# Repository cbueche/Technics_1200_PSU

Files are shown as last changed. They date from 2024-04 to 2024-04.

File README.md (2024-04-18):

# DC PSU for the Technics SL-1200 

An external PSU (linear power supply unit) for the Technics SL-1200 turntable. Originaly designed by user 6L6 published on DIYaudio.com forum in 2013.

## License

This project is licensed under the terms of the CERN Open Hardware Licence Version 2, permissive variant [CERN-OHL-P](cern_ohl_p_v2).

## Schematics

The [schematic](schema_v4.pdf) is an export from the kicad files.

## PCB

I designed a PCB for this project, the [kicad](kicad/) directory contains everything needed : the schematic, the PCB design, etc. I updated those files to Kicad 8. There is a zip file that I was able to use to order 5 PCBs from PCBway, the minimal order quantity was 5 in May 2023. The four remaining PCBs were sold quickly.

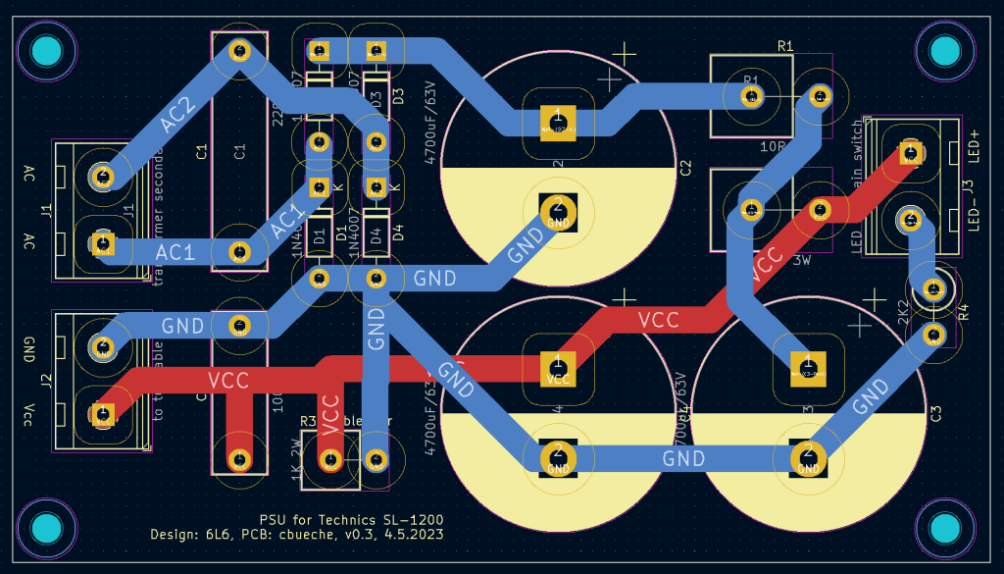
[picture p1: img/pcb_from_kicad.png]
PCB


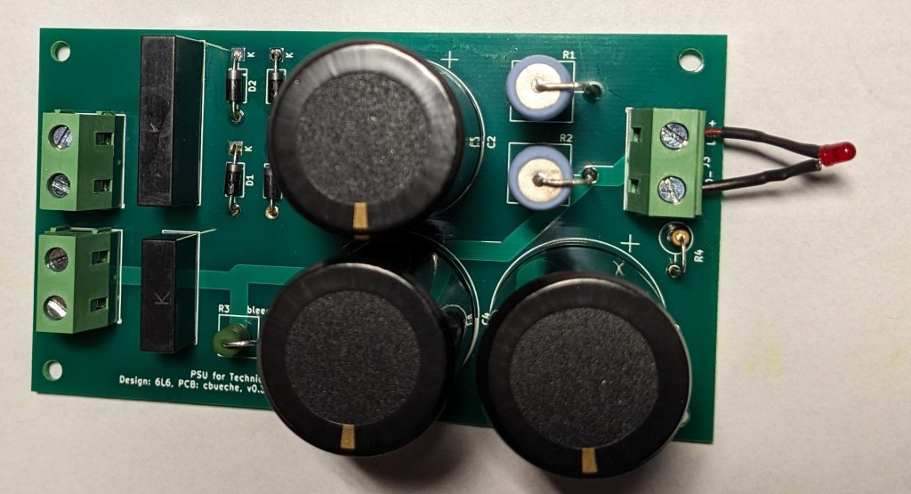
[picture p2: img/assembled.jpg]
assembled


The side-holes are not connected to anything, proper grounding is your task. I recommend connecting the input earth to the case. As designed, the DC output (GND and Vcc) are floating.

## BOM

Sorry, no BOM, see the CSV file in the [kicad](kicad/) directory, the footprint column provides some info on the spacing. In general, very standard components can be used. Big capacitors are 10mm snap-in, connectors use 7.5mm spacing.

## Resources

- the [original thread](https://www.diyaudio.com/community/threads/technics-sl-1200-dc-power-supply.238618/) on DIYaudio
- original author : 6L6, DIYaudio.com

## concept used in my personal case

- external DC PSU unit
- regulator and probe switch from [KAB USA](https://www.kabusa.com)

## case

The original transformer and this PCB did somewhat tightly fit into a Hifi 2000 Galaxy case model GX183 (80x124x230). A tight fit so check before drilling holes.

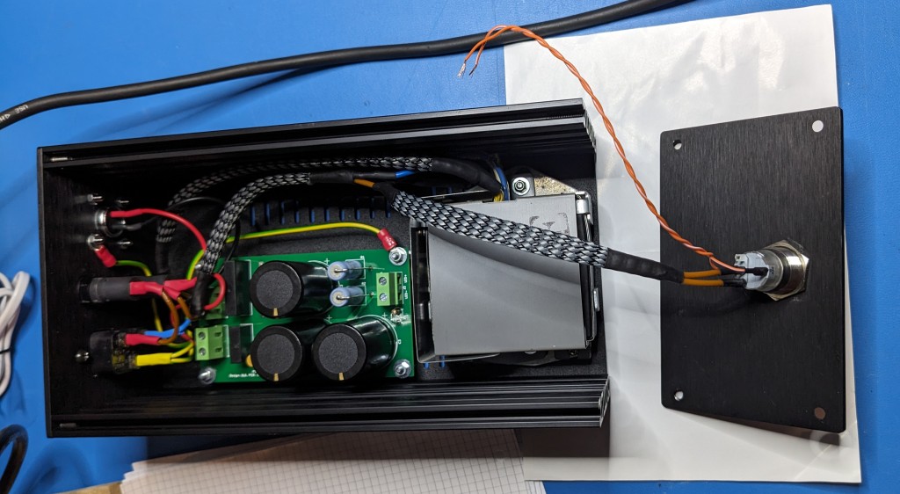
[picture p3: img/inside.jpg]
inside


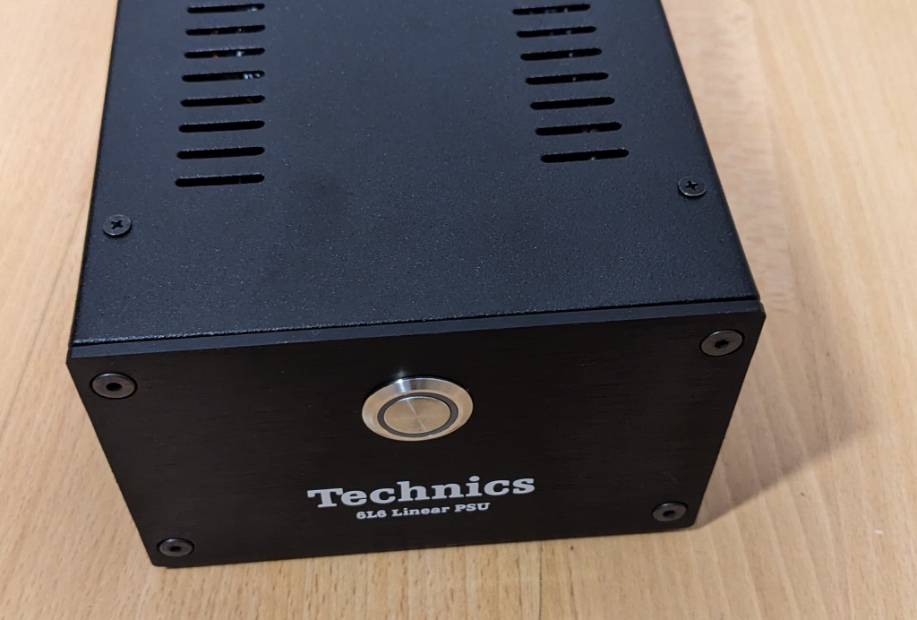
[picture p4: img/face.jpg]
face


## fuses

These fuse values are appropriate for 230V.

- top, input : AC, T 250 mA
- bottom, output : DC, T 1 A

## DC cable

- 2 x 0.75
- pin 1 : brown : GND
- pin 2 : blue : Vcc

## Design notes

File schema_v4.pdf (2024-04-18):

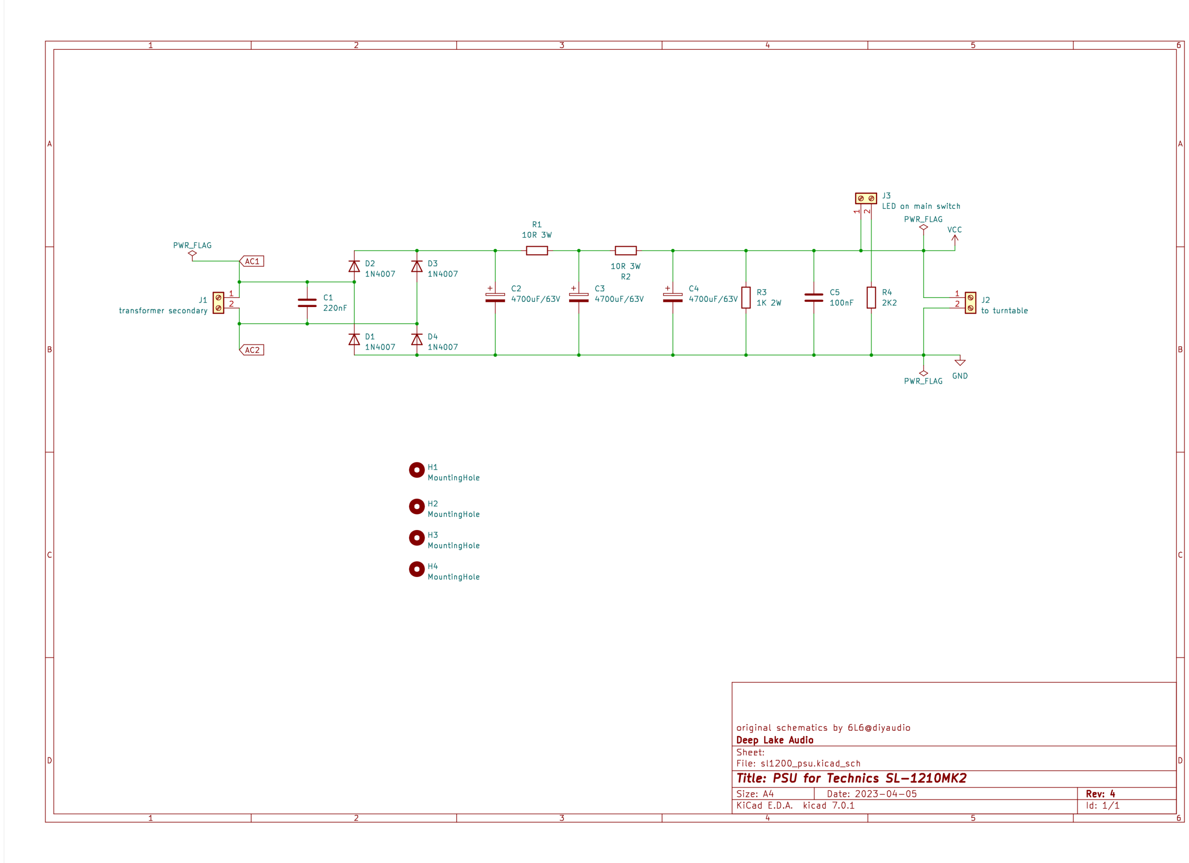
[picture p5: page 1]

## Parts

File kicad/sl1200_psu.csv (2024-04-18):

Source: | /home/cbueche/Data/Audio/tourne_disque/Technics_1210_MK2/PSU/kicad/sl1200_psu.kicad_sch
Date: | Thu Mar 9 16:44:58 2023
Tool: | Eeschema (7.0.0)
Generator: | /usr/share/kicad/plugins/bom_csv_grouped_by_value_with_fp.py
Component Count: | 16
Ref | Qnty | Value | Cmp name | Footprint | Description | Vendor | DNP
C1 | 1 | 220nF | C | Capacitor_THT:C_Rect_L26.5mm_W6.0mm_P22.50mm_MKS4 | Unpolarized capacitor
C2, C3, C4 | 3 | 4700uF/63V | C_Polarized | Capacitor_THT:CP_Radial_D26.0mm_P10.00mm_SnapIn | Polarized capacitor
C5 | 1 | 100nF | C | Capacitor_THT:C_Rect_L26.5mm_W6.0mm_P22.50mm_MKS4 | Unpolarized capacitor
D1, D2, D3, D4 | 4 | 1N4007 | 1N4007 | Diode_THT:D_DO-41_SOD81_P10.16mm_Horizontal | 1000V 1A General Purpose Rectifier Diode, DO-41
J1 | 1 | transformer secondary | Screw_Terminal_01x02 | TerminalBlock_RND:TerminalBlock_RND_205-00067_1x02_P7.50mm_Horizontal | Generic screw terminal, single row, 01x02, script generated (kicad-library-utils/schlib/autogen/connector/)
J2 | 1 | to turntable | Screw_Terminal_01x02 | TerminalBlock_RND:TerminalBlock_RND_205-00067_1x02_P7.50mm_Horizontal | Generic screw terminal, single row, 01x02, script generated (kicad-library-utils/schlib/autogen/connector/)
J3 | 1 | LED on main switch | Screw_Terminal_01x02 | TerminalBlock_RND:TerminalBlock_RND_205-00067_1x02_P7.50mm_Horizontal | Generic screw terminal, single row, 01x02, script generated (kicad-library-utils/schlib/autogen/connector/)
R1, R2 | 2 | 10R 3W | R | Resistor_THT:R_Axial_Power_L38.0mm_W9.0mm_P40.64mm | Resistor
R3 | 1 | 1K 2W | R | Resistor_THT:R_Axial_Power_L20.0mm_W6.4mm_P5.08mm_Vertical | Resistor
R4 | 1 | 2K2 2W | R | Resistor_THT:R_Axial_Power_L20.0mm_W6.4mm_P5.08mm_Vertical | Resistor

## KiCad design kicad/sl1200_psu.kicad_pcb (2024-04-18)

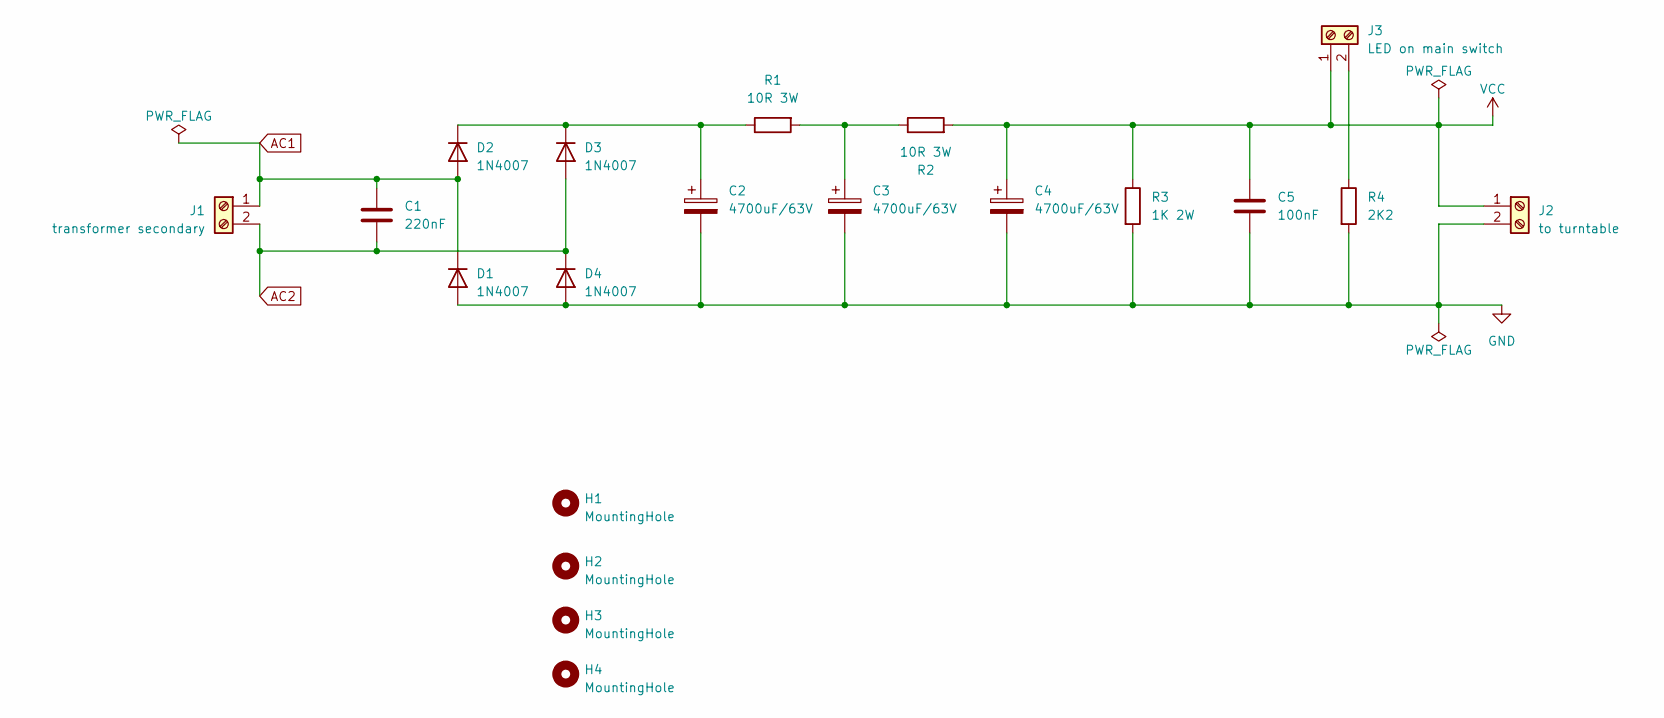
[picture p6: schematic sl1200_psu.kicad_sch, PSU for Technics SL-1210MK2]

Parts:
C1: 220nF; C_Rect_L26.5mm_W6.0mm_P22.50mm_MKS4
C2, C3, C4: 4700uF/63V; CP_Radial_D26.0mm_P10.00mm_SnapIn
C5: 100nF; C_Rect_L18.0mm_W6.0mm_P15.00mm_FKS3_FKP3
D1, D2, D3, D4: 1N4007; D_DO-41_SOD81_P10.16mm_Horizontal
H1, H2, H3, H4: MountingHole; MountingHole_3.2mm_M3
J1: transformer secondary; TerminalBlock_RND_205-00067_1x02_P7.50mm_Horizontal
J2: to turntable; TerminalBlock_RND_205-00067_1x02_P7.50mm_Horizontal
J3: LED on main switch; TerminalBlock_RND_205-00067_1x02_P7.50mm_Horizontal
R1, R2: 10R 3W; R_Axial_Power_L25.0mm_W9.0mm_P7.62mm_Vertical
R3: 1K 2W; R_Axial_Power_L20.0mm_W6.4mm_P5.08mm_Vertical
R4: 2K2; R_Axial_DIN0414_L11.9mm_D4.5mm_P5.08mm_Vertical

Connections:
AC1: C1.1, D1.1 (K), D2.2 (A), J1.1
AC2: C1.2, D3.2 (A), D4.1 (K), J1.2
GND: C2.2, C3.2, C4.2, C5.2, D1.2 (A), D4.2 (A), J2.2, R3.2, R4.2
unnamed: C3.1, R1.2, R2.1
unnamed: C2.1, D2.1 (K), D3.1 (K), R1.1
unnamed: J3.2, R4.1
VCC: C4.1, C5.1, J2.1, J3.1, R2.2, R3.1

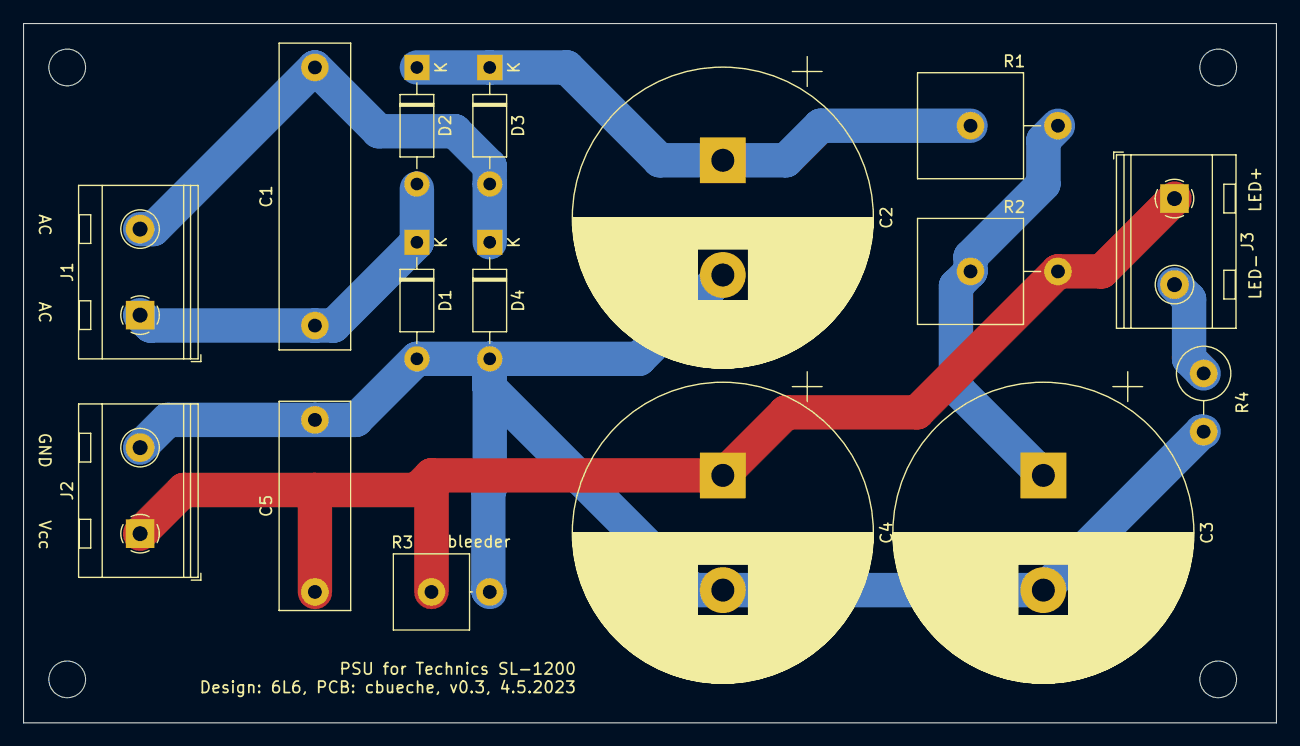
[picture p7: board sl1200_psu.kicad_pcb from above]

Board: 2 copper layers, 109.2 x 61.0 mm, 20 parts (0 on the bottom side), 7 nets.
